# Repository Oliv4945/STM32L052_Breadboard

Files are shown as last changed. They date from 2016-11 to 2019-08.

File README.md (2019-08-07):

# STM32L052 Breadboard
Small breadboard compatible development board designed for STM32L052, but all STM32 in LQFP32 package should fit.

# Requirements
* Breakout all I/Os
* WS2812 RGB led, blinky things, you know !
* 3.3V LDO regulator
* Easy way to select Vin or Vusb (jumper)
* Easy way to select `BOOT0` (jumper)
* USB connector and ESD protection
* 200 to 300 mA mosfet in order to control a more power or other voltages
* Reset button
* Breadboard friendly
* "FTDI" pinout connector for serial communications, and to try ST serial bootloader
* All components on one side, so the board can be easily reflowed with hotplate

# Toolchain
Example projets are for Eclipse/OpenSTM32/GCC-ARM, also CubeMX project file is given so it should be easy to generate project files for other IDE.

# Code examples
There is few snippets of code in master branch, regarding:
* WS2812b led
* MOSFET control
* RTC  

In USB_HID branch, there is custom USB_HID device which allows consumer device (media keys) + keyboard

# Others
More info [here](http://notes.iopush.net/stm32l052-development-board/).  
Hardware is under CC Attribution-ShareAlike 3.0 license.

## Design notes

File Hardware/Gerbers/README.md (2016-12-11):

Gerbers generated thanks to [Dirty PCB CAM rules](http://dirtypcbs.com/store/pcbs/about)

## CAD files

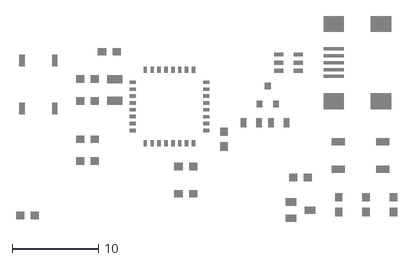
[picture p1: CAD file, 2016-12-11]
Hardware/Gerbers/STM32L052_Breadboard_3mil.dxf
44.3 x 23.9

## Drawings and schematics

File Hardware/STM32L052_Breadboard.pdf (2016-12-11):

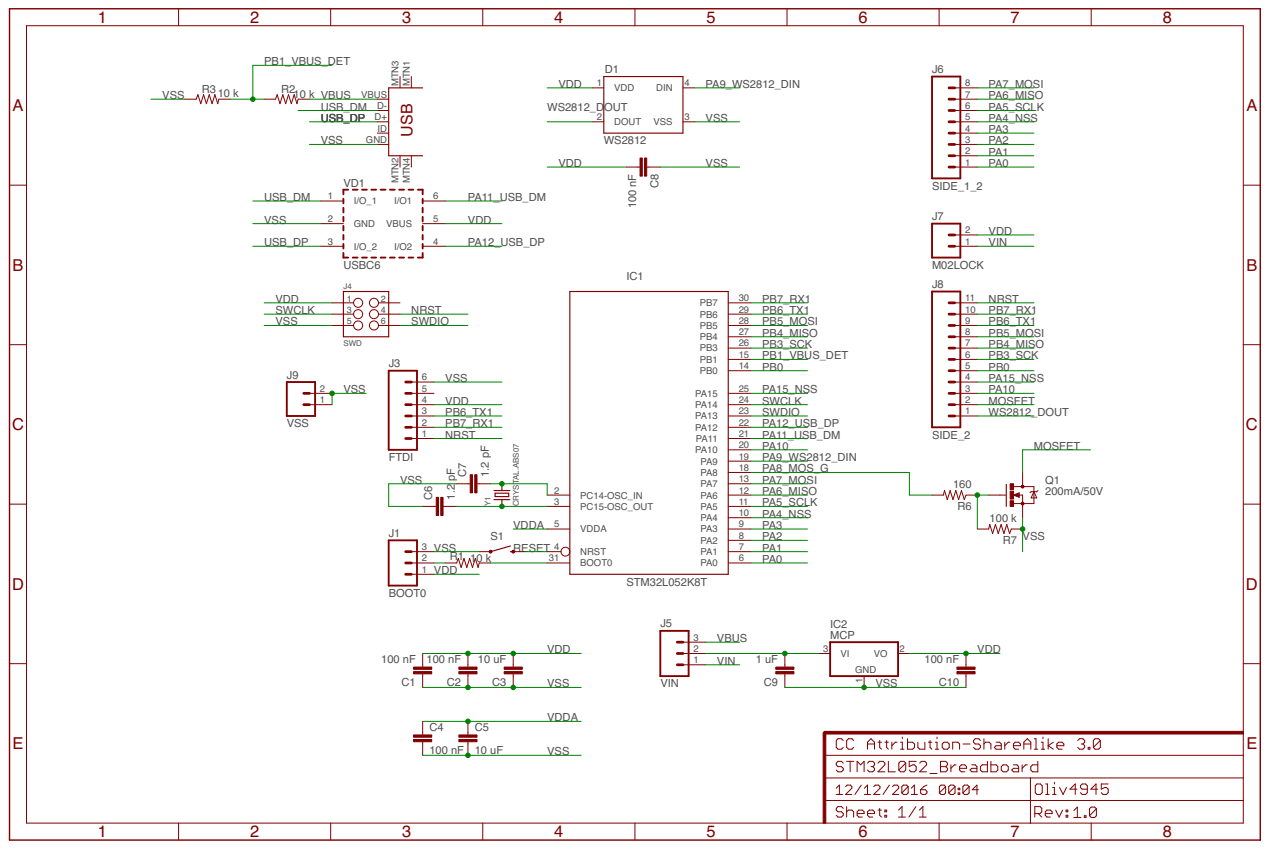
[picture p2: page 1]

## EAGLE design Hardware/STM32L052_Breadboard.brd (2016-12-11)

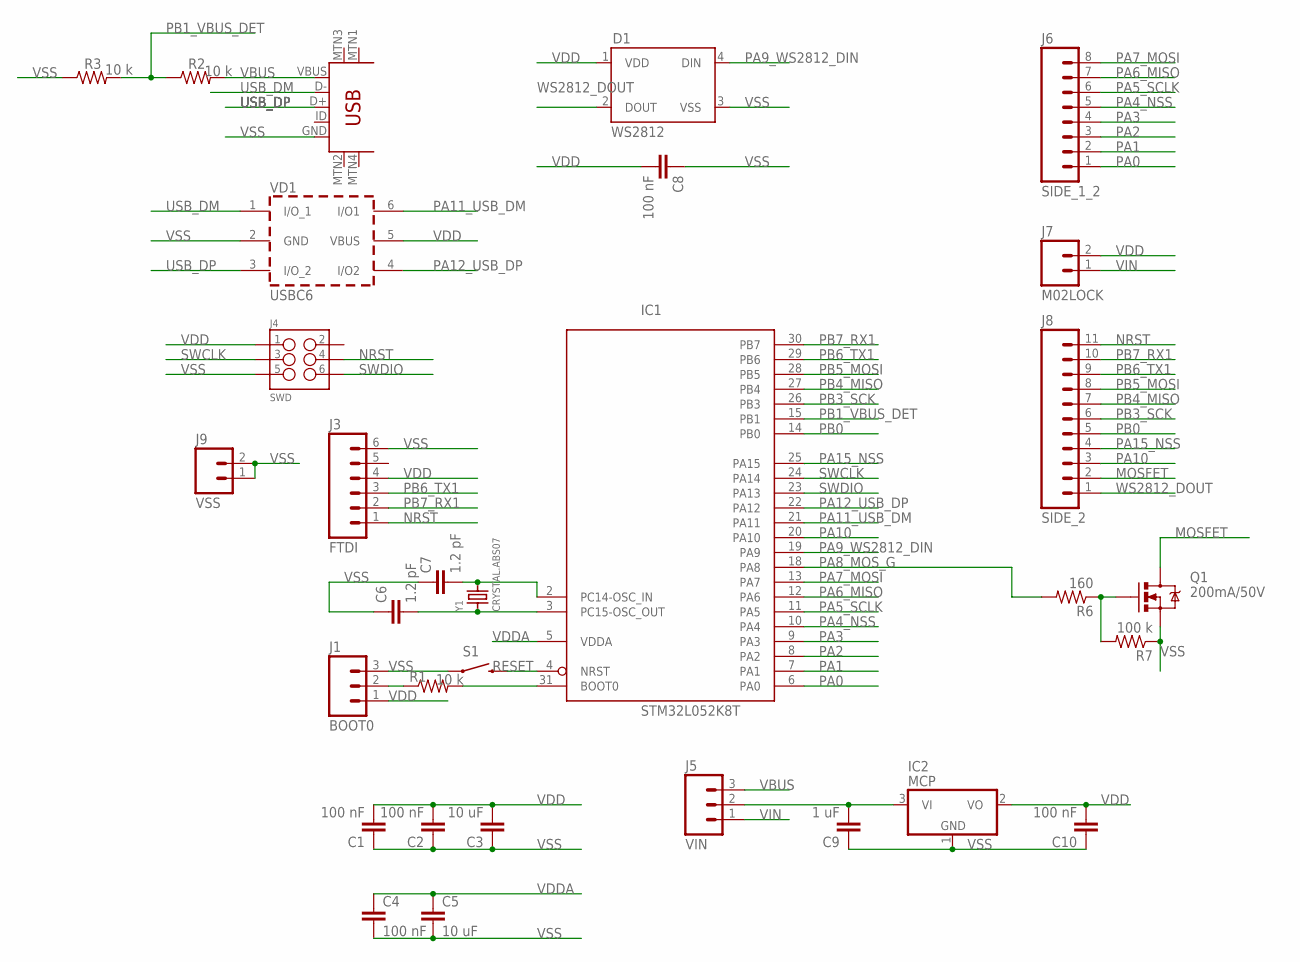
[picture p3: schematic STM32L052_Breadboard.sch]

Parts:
C1, C2, C4, C8, C10: 100 nF; 0603-CAP
C3, C5: 10 uF; 0603-CAP
C6, C7: 1.2 pF; 0603-CAP
C9: 1 uF; 0603-CAP
D1: WS2812; WS2812B
IC1: STM32L052K8T; LQFP32
IC2: MCP; SOT23
J1: BOOT0; 1X03_LOCK
J3: FTDI; 1X06_LOCK
J4: SWD; 2X3
J5: VIN; 1X03_LOCK
J6: SIDE_1_2; 1X08_LOCK
J7: M02LOCK; 1X02_LOCK
J8: SIDE_2; 1X11_LOCK
J9: VSS; 1X02_LOCK
Q1: 200mA/50V; SOT23-3
R1, R2, R3: 10 k; 0603-RES
R6: 160; 0805
R7: 100 k; 0805
S1: RESET; TACTILE-SWITCH-SMD
U$1: USB-MINIB-5PIN; USB-MINIB
VD1: USBC6; SOT-23-6L
Y1: CRYSTAL.ABS07; ABS07

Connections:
BOOT0: IC1.31 (BOOT0), R1.2
BOOT0_SEL: J1.2, R1.1
MOSFET: J8.2, Q1.3 (D)
unnamed: Q1.1 (G), R6.1, R7.2
NRST: IC1.4 (NRST), J3.1, J4.4, J8.11, S1.3 (2)
OSC_IN: C7.2, IC1.2 (PC14-OSC_IN), Y1.2
OSC_OUT: C6.2, IC1.3 (PC15-OSC_OUT), Y1.1
PA0: IC1.6 (PA0), J6.1
PA1: IC1.7 (PA1), J6.2
PA2: IC1.8 (PA2), J6.3
PA3: IC1.9 (PA3), J6.4
PA4_NSS: IC1.10 (PA4), J6.5
PA5_SCLK: IC1.11 (PA5), J6.6
PA6_MISO: IC1.12 (PA6), J6.7
PA7_MOSI: IC1.13 (PA7), J6.8
PA8_MOS_G: IC1.18 (PA8), R6.2
PA9_WS2812_DIN: D1.4 (DIN), IC1.19 (PA9)
PA10: IC1.20 (PA10), J8.3
PA11_USB_DM: IC1.21 (PA11), VD1.6 (I/O1)
PA12_USB_DP: IC1.22 (PA12), VD1.4 (I/O2)
PA15_NSS: IC1.25 (PA15), J8.4
PB0: IC1.14 (PB0), J8.5
PB1_VBUS_DET: IC1.15 (PB1), R2.1, R3.2
PB3_SCK: IC1.26 (PB3), J8.6
PB4_MISO: IC1.27 (PB4), J8.7
PB5_MOSI: IC1.28 (PB5), J8.8
PB6_TX1: IC1.29 (PB6), J3.3, J8.9
PB7_RX1: IC1.30 (PB7), J3.2, J8.10
SWCLK: IC1.24 (PA14), J4.3
SWDIO: IC1.23 (PA13), J4.6
USB_DM: U$1.D-, VD1.1 (I/O_1)
USB_DP: U$1.D+, VD1.3 (I/O_2)
VBUS: J5.3, R2.2, U$1.VBUS
VDD: C1.2, C2.2, C3.2, C8.2, C10.2, D1.1 (VDD), IC1.1 (VDD), IC1.17 (VDD), IC2.2 (VO), J1.1, J3.4, J4.1, J7.2, VD1.5 (VBUS)
VDDA: C4.1, C5.1, IC1.5 (VDDA)
VIN: J5.1, J7.1
VIN_ALL: C9.2, IC2.3 (VI), J5.2
VSS: C1.1, C2.1, C3.1, C4.2, C5.2, C6.1, C7.1, C8.1, C9.1, C10.1, D1.3 (VSS), IC1.16 (VSS), IC1.32 (VSS), IC2.1 (GND), J1.3, J3.6, J4.5, J9.1, J9.2, Q1.2 (S), R3.1, R7.1, S1.1, U$1.GND, VD1.2 (GND)
WS2812_DOUT: D1.2 (DOUT), J8.1

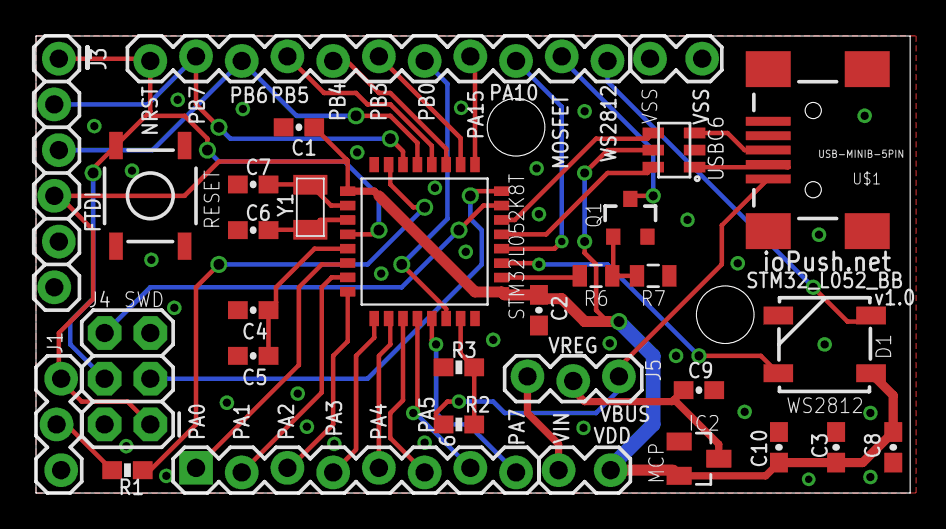
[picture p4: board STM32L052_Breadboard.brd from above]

Board: 2 copper layers, 48.6 x 25.4 mm, 31 parts (0 on the bottom side), 39 nets.

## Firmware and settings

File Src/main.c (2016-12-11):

/**
  ******************************************************************************
  * File Name          : main.c
  * Description        : Main program body
  ******************************************************************************
  *
  * COPYRIGHT(c) 2016 STMicroelectronics
  *
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
  ******************************************************************************
  */
/* Includes ------------------------------------------------------------------*/
#include "main.h"
#include "stm32l0xx_hal.h"
#include "rtc.h"
#include "usart.h"
#include "gpio.h"


/* USER CODE BEGIN PV */

/* USER CODE END PV */

void SystemClock_Config(void);
void Error_Handler(void);

/* USER CODE BEGIN PFP */

/* USER CODE END PFP */

int main(void)
{

  /* USER CODE BEGIN 1 */
  RTC_TimeTypeDef sTime;
  RTC_DateTypeDef sDate;

  // WS2812
  uint8_t green[] = {0x1F, 0x00, 0x00};
  uint8_t red[]   = {0x00, 0x1F, 0x00};
  uint8_t blue[]  = {0x00, 0x00, 0x1F};
  uint8_t black[] = {0x00, 0x00, 0x00};
  //uint8_t colors[3][3] = { {0x1F, 0x00, 0x00}, {0x00, 0x1F, 0x00}, {0x00, 0x00, 0x1F} };
  uint8_t *colors[] = { green, red, blue };
  uint8_t colorsIndex = 0;

  /* USER CODE END 1 */

  /* MCU Configuration----------------------------------------------------------*/

  /* Reset of all peripherals, Initializes the Flash interface and the Systick. */
  HAL_Init();

  /* Configure the system clock */
  SystemClock_Config();

  /* Initialize all configured peripherals */
  MX_GPIO_Init();
  MX_RTC_Init();
  MX_USART1_UART_Init();

  /* USER CODE BEGIN 2 */
  HAL_printf("Starting STM32L052_BB_Tests\n");

  // RTC settings
  sTime.Hours = 0;
  sTime.Minutes = 12;
  sTime.Seconds = 0;
  sTime.DayLightSaving = RTC_DAYLIGHTSAVING_NONE;
  sTime.StoreOperation = RTC_STOREOPERATION_RESET;
  sDate.WeekDay = RTC_WEEKDAY_TUESDAY;
  sDate.Month = RTC_MONTH_NOVEMBER;
  sDate.Date = 29;
  sDate.Year = 16;
  if (HAL_RTC_SetTime(&hrtc, &sTime, RTC_FORMAT_BIN) != HAL_OK) {
    Error_Handler();
  }
  if (HAL_RTC_SetDate(&hrtc, &sDate, RTC_FORMAT_BIN) != HAL_OK) {
    Error_Handler();
  }



  /* USER CODE END 2 */

  /* Infinite loop */
  /* USER CODE BEGIN WHILE */
  while (1)
  {
  /* USER CODE END WHILE */

  /* USER CODE BEGIN 3 */
    // RTC
    HAL_RTC_GetTime(&hrtc, &sTime, RTC_FORMAT_BIN);
    HAL_RTC_GetDate(&hrtc, &sDate, RTC_FORMAT_BIN);
    HAL_printf("Date : %02d/%02d/20%02d %02d:%02d:%02d\n", sDate.Date, sDate.Month, sDate.Year, sTime.Hours, sTime.Minutes, sTime.Seconds);

    HAL_printf("\n");
    HAL_GPIO_TogglePin(MOSFET_GPIO_Port, MOSFET_Pin);
    ws2812_sendarray(colors[colorsIndex], 3);
    colorsIndex = (colorsIndex+1) % 3;
    HAL_Delay(1000);

  }
  /* USER CODE END 3 */

}

/** System Clock Configuration
*/
void SystemClock_Config(void)
{

  RCC_OscInitTypeDef RCC_OscInitStruct;
  RCC_ClkInitTypeDef RCC_ClkInitStruct;
  RCC_PeriphCLKInitTypeDef PeriphClkInit;

    /**Configure the main internal regulator output voltage 
    */
  __HAL_PWR_VOLTAGESCALING_CONFIG(PWR_REGULATOR_VOLTAGE_SCALE1);

    /**Initializes the CPU, AHB and APB busses clocks 
    */
  RCC_OscInitStruct.OscillatorType = RCC_OSCILLATORTYPE_HSI|RCC_OSCILLATORTYPE_LSE;
  RCC_OscInitStruct.LSEState = RCC_LSE_ON;
  RCC_OscInitStruct.HSIState = RCC_HSI_ON;
  RCC_OscInitStruct.HSICalibrationValue = 16;
  RCC_OscInitStruct.PLL.PLLState = RCC_PLL_NONE;
  if (HAL_RCC_OscConfig(&RCC_OscInitStruct) != HAL_OK)
  {
    Error_Handler();
  }

    /**Initializes the CPU, AHB and APB busses clocks 
    */
  RCC_ClkInitStruct.ClockType = RCC_CLOCKTYPE_HCLK|RCC_CLOCKTYPE_SYSCLK
                              |RCC_CLOCKTYPE_PCLK1|RCC_CLOCKTYPE_PCLK2;
  RCC_ClkInitStruct.SYSCLKSource = RCC_SYSCLKSOURCE_HSI;
  RCC_ClkInitStruct.AHBCLKDivider = RCC_SYSCLK_DIV1;
  RCC_ClkInitStruct.APB1CLKDivider = RCC_HCLK_DIV1;
  RCC_ClkInitStruct.APB2CLKDivider = RCC_HCLK_DIV1;

  if (HAL_RCC_ClockConfig(&RCC_ClkInitStruct, FLASH_LATENCY_0) != HAL_OK)
  {
    Error_Handler();
  }

  PeriphClkInit.PeriphClockSelection = RCC_PERIPHCLK_USART1|RCC_PERIPHCLK_RTC;
  PeriphClkInit.Usart1ClockSelection = RCC_USART1CLKSOURCE_PCLK2;
  PeriphClkInit.RTCClockSelection = RCC_RTCCLKSOURCE_LSE;
  if (HAL_RCCEx_PeriphCLKConfig(&PeriphClkInit) != HAL_OK)
  {
    Error_Handler();
  }

    /**Configure the Systick interrupt time 
    */
  HAL_SYSTICK_Config(HAL_RCC_GetHCLKFreq()/1000);

    /**Configure the Systick 
    */
  HAL_SYSTICK_CLKSourceConfig(SYSTICK_CLKSOURCE_HCLK);

  /* SysTick_IRQn interrupt configuration */
  HAL_NVIC_SetPriority(SysTick_IRQn, 0, 0);
}

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


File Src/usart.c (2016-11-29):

/**
  ******************************************************************************
  * File Name          : USART.c
  * Description        : This file provides code for the configuration
  *                      of the USART instances.
  ******************************************************************************
  *
  * COPYRIGHT(c) 2016 STMicroelectronics
  *
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
  ******************************************************************************
  */

/* Includes ------------------------------------------------------------------*/
#include "usart.h"

#include "gpio.h"

UART_HandleTypeDef huart1;

/* USART1 init function */

void MX_USART1_UART_Init(void)
{

  huart1.Instance = USART1;
  huart1.Init.BaudRate = 115200;
  huart1.Init.WordLength = UART_WORDLENGTH_8B;
  huart1.Init.StopBits = UART_STOPBITS_1;
  huart1.Init.Parity = UART_PARITY_NONE;
  huart1.Init.Mode = UART_MODE_TX_RX;
  huart1.Init.HwFlowCtl = UART_HWCONTROL_NONE;
  huart1.Init.OverSampling = UART_OVERSAMPLING_16;
  huart1.Init.OneBitSampling = UART_ONE_BIT_SAMPLE_DISABLE;
  huart1.AdvancedInit.AdvFeatureInit = UART_ADVFEATURE_NO_INIT;
  if (HAL_UART_Init(&huart1) != HAL_OK)
  {
    Error_Handler();
  }

}

void HAL_UART_MspInit(UART_HandleTypeDef* uartHandle)
{

  GPIO_InitTypeDef GPIO_InitStruct;
  if(uartHandle->Instance==USART1)
  {
    /* Peripheral clock enable */
    __HAL_RCC_USART1_CLK_ENABLE();
  
    /**USART1 GPIO Configuration    
    PB6     ------> USART1_TX
    PB7     ------> USART1_RX 
    */
    GPIO_InitStruct.Pin = GPIO_PIN_6|GPIO_PIN_7;
    GPIO_InitStruct.Mode = GPIO_MODE_AF_PP;
    GPIO_InitStruct.Pull = GPIO_PULLUP;
    GPIO_InitStruct.Speed = GPIO_SPEED_FREQ_VERY_HIGH;
    GPIO_InitStruct.Alternate = GPIO_AF0_USART1;
    HAL_GPIO_Init(GPIOB, &GPIO_InitStruct);

  }
}

void HAL_UART_MspDeInit(UART_HandleTypeDef* uartHandle)
{

  if(uartHandle->Instance==USART1)
  {
    /* Peripheral clock disable */
    __HAL_RCC_USART1_CLK_DISABLE();
  
    /**USART1 GPIO Configuration    
    PB6     ------> USART1_TX
    PB7     ------> USART1_RX 
    */
    HAL_GPIO_DeInit(GPIOB, GPIO_PIN_6|GPIO_PIN_7);

  }
} 

/* USER CODE BEGIN 1 */
/** Generic LOG procedure
 * @param level
 * @param *fmt String to print
 * @param argp Parameters list
 */
static void emplLog(uint8_t level, const char *fmt, va_list argp) {
  HAL_printf("%c - ", level);
  HAL_printf_valist(fmt, argp);
}

/** LOG procedure - Info
 * @param *fmt String to print
 * @param ... Parameters list
 */
void emplLogI(const char* fmt, ...) {
  va_list argp;

  va_start(argp, fmt);
  emplLog('I', fmt, argp);
  va_end(argp);
}

/** LOG procedure - Error
 * @param *fmt String to print
 * @param ... Parameters list
 */
void emplLogE(const char* fmt, ...) {
  va_list argp;

  va_start(argp, fmt);
  emplLog('E', fmt, argp);
  va_end(argp);
}

/** Custom printf function in order to use HAL_UART_Transmit()
 * @param *fmt String to print
 * @param argp Parameters list
 */
void HAL_printf_valist(const char *fmt, va_list argp) {
  char string[PRINT_BUFFER_SIZE];

  if (vsprintf(string,fmt,argp) > 0) {
    HAL_UART_Transmit(&HAL_PRINT_UART, (uint8_t*)string, strlen(string), HAL_MAX_DELAY); // send message via UART
  } else {
  HAL_UART_Transmit(&HAL_PRINT_UART, (uint8_t*)"E - Print\n", 14, HAL_MAX_DELAY);
  }
}

/** Custom printf function, only translate to va_list arg HAL_UART.
 * @param *fmt String to print
 * @param ... Data
 */
void HAL_printf(const char *fmt, ...) {
  va_list argp;

  va_start(argp, fmt);
  HAL_printf_valist(fmt, argp);
  va_end(argp);
}
/* USER CODE END 1 */

/**
  * @}
  */

/**
  * @}
  */

/************************ (C) COPYRIGHT STMicroelectronics *****END OF FILE****/

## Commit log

2016-12-11 Switch RTC to binary mode
2016-12-11 Add MOSFET
2016-12-11 Switch light_ws2812 to forked repository
2016-12-11 Add hardware design files
    [STM32L052_Breadboard.GBL, STM32L052_Breadboard.GBO, STM32L052_Breadboard.GBP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]

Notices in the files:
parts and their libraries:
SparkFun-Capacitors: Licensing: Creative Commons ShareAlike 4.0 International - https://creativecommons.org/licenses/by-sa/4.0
